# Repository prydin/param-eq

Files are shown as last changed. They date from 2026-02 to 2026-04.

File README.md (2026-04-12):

# Parametric EQ to DSP Playground

This project started as a focused experiment: build a practical, hardware-controlled parametric equalizer.
Along the way it grew into something broader: a general-purpose DSP platform for real-time audio processing,
instrumentation, and UI experiments.

What began as "just three EQ bands" now includes filter control, combined response visualization,
VU metering, spectrum visualization, and a register-based control/data protocol between two MCUs.

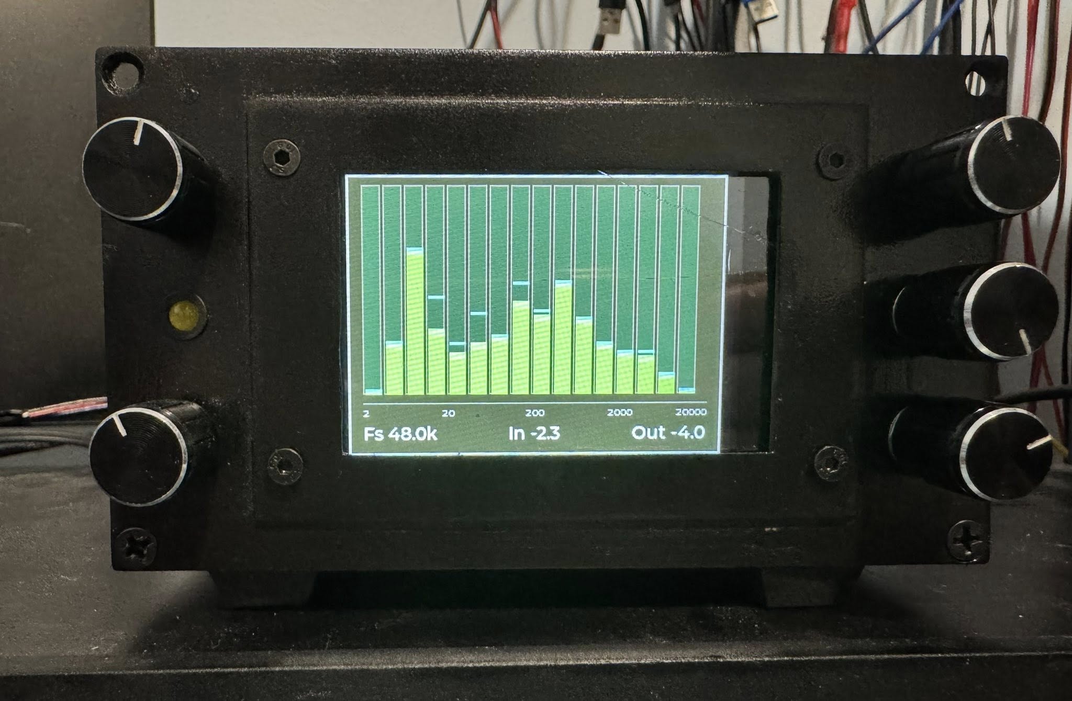
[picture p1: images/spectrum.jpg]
Spectrum

Filter design
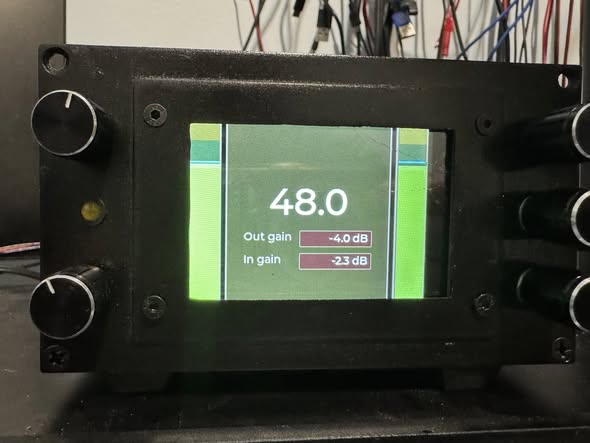
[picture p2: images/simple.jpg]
Simple UI

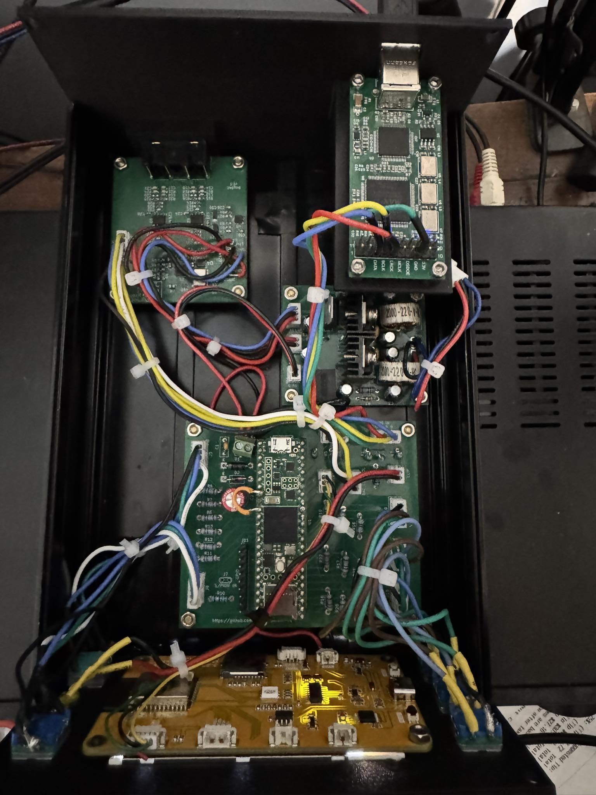
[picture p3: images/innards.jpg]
Interior


## Project Story

The original goal was simple:

1. Build a hands-on parametric EQ with physical controls.
2. Show the selected filter behavior and resulting response in real time.
3. Keep the software and hardware open enough to keep evolving.

That third point changed everything. Once the DSP core and UI link were stable, it became obvious that
the architecture could do far more than EQ alone. The codebase now behaves more like a modular DSP
workbench than a single-purpose effect.

## Architecture

The system uses two processors, each doing the job it is best at.

### Teensy 4.1: Audio DSP Engine

- Handles real-time signal processing.
- Computes filter behavior and response data.
- Publishes metering and spectrum data.
- Maintains the parameter/register state that the UI consumes.

Why Teensy 4.1:

- Cortex-M7 performance is excellent for this class of project.
- Floating-point math is fast enough to keep filter code readable and robust.
- Great ecosystem for embedded audio prototyping.

### ESP32 CYD: UI Processor

The UI runs on a CYD (Cheap Yellow Display), which is an ESP32-based board with an integrated TFT.

- Renders LVGL-based UI modes.
- Reads user input from rotary encoders/buttons.
- Displays EQ response, VU, and spectrum information.
- Exchanges register updates with the Teensy via I2C.

### Interconnect: Register-Based I2C Protocol

Communication between DSP and UI uses compact register messages over I2C.

- Control parameters and mode changes flow from UI-side interactions.
- DSP publishes status, levels, and spectrum bins back to UI.
- Commit-style register updates keep state transitions predictable.

## UI Modes

The UI currently provides three main modes, each optimized for a different use case.

### 1) Detailed EQ Mode

Purpose: precise tuning and analysis.

- Displays selected filter response and optional combined response.
- Shows active filter type and selected filter band.
- Shows numeric parameter values including frequency, gain, Q, sample rate, and level settings.
- Intended for surgical parameter work.

### 2) Simple Meter Mode

Purpose: quick operating view.

- Large, easy-to-read core values.
- Stereo VU metering with ballistic behavior and peak hold.
- Designed for "use while listening" rather than deep editing.

### 3) Spectrum Analyzer Mode

Purpose: visualize real-time spectral behavior.

- Real-time spectrum bars with smoothing and peak hold.
- Log-style frequency scale and supplemental operating info.
- Useful for spotting trends, resonances, and level distribution.

### Filter Parameter Popup Overlay

When operating in Simple or Spectrum mode, parameter changes can trigger a framed popup showing key
filter settings (band, type, frequency, gain, and Q). The popup auto-hides after inactivity, and can
be gated by user-input state so remote/background updates do not constantly interrupt the view.

## Current Scope

- Multi-band parametric EQ control.
- Low shelf, high shelf, and peak filter workflows.
- Dual-MCU DSP/UI split with robust register transport.
- Multiple operator-focused UI modes.
- Real-time VU and spectrum visualization.

## Where It Is Heading

Long term, the plan is to fold this work into a DAC/DSP/preamplifier build.
This repository is the proving ground for that hardware/software stack.

## Acknowledgements

Big thanks to the diyAudio.com community.

Many design choices, implementation refinements, and troubleshooting ideas were inspired by the
knowledge shared by diyAudio members. The project benefited directly from their practical guidance,
experience, and generosity in public discussion threads.

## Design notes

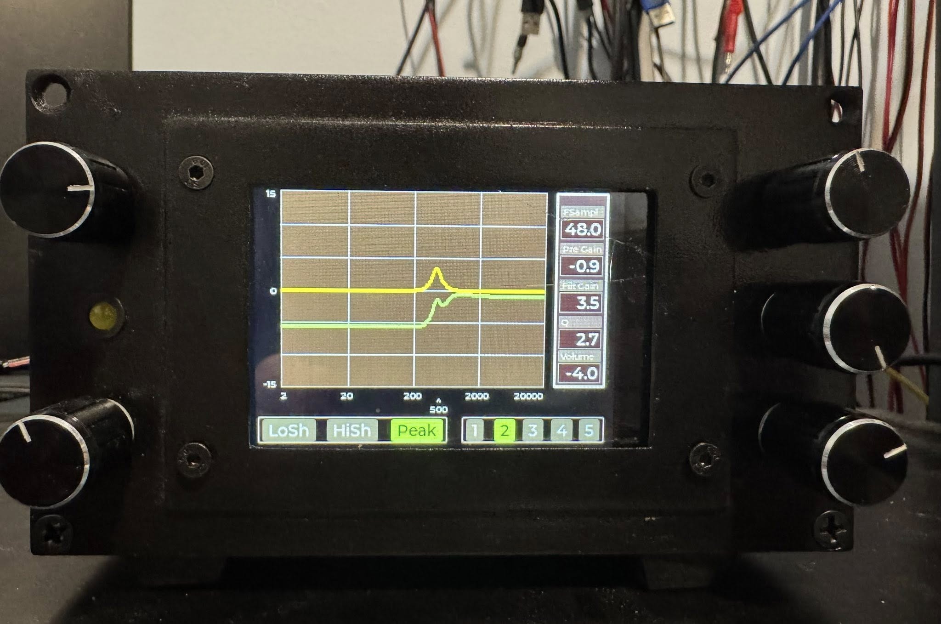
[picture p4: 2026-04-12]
images/eq.jpg

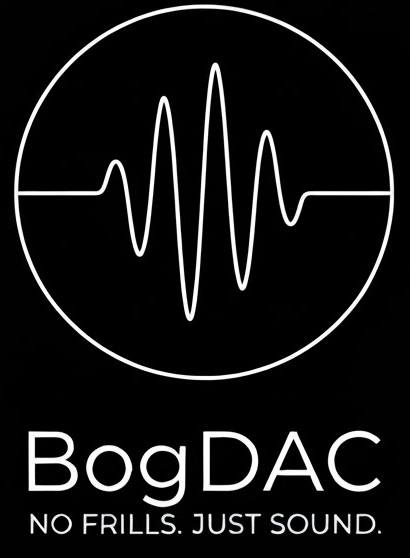
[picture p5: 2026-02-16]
kicad/dac/bogdac.jpg

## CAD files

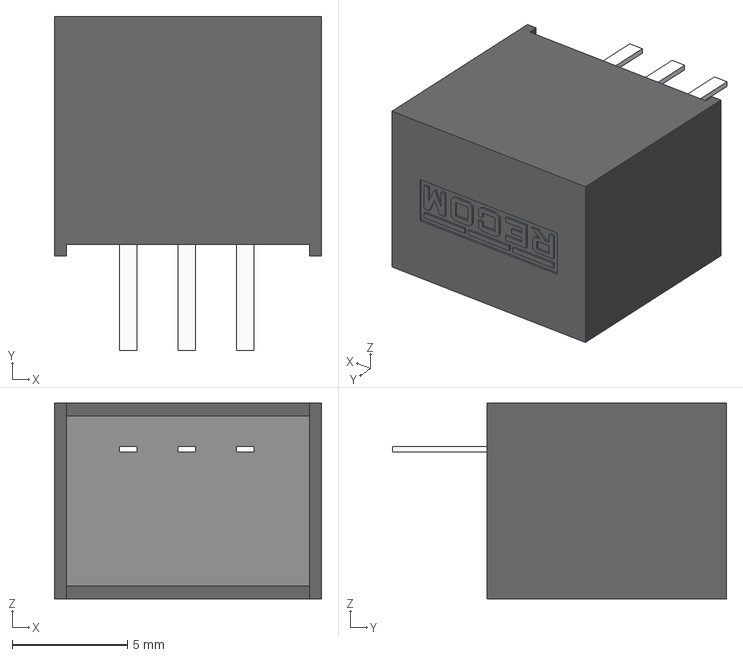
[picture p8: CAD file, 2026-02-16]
kicad/regulator/footprints/R-78E5.0-1.0.step
11.6 x 14.5 x 8.50 mm

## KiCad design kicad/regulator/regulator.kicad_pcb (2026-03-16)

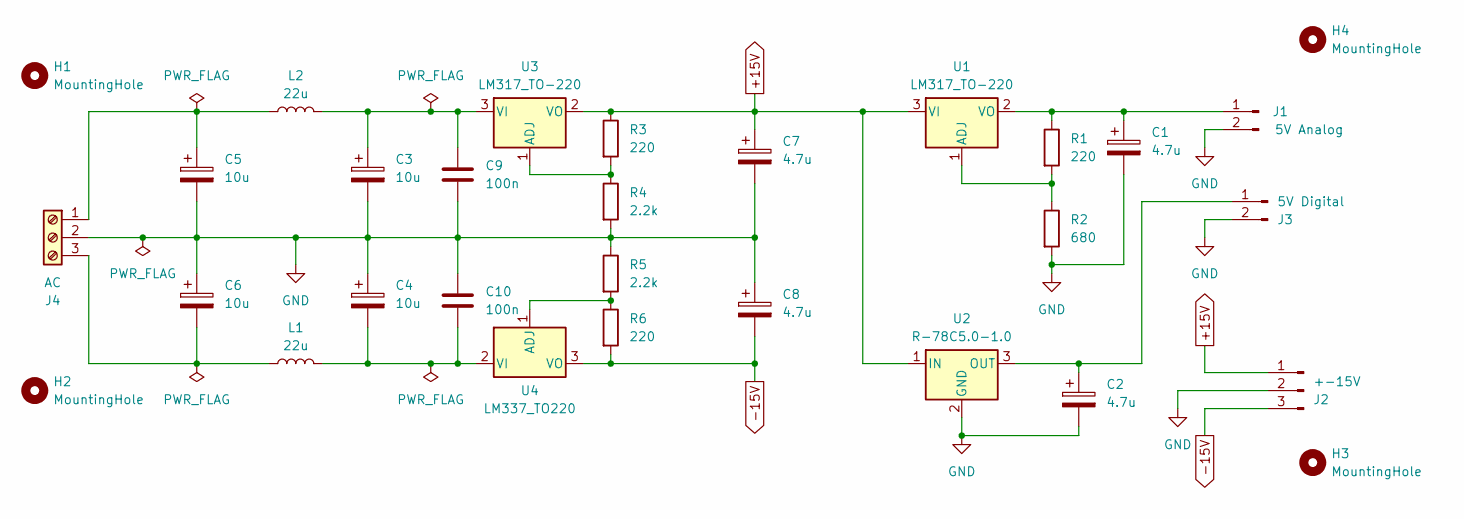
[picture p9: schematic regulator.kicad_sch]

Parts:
C1, C2, C7, C8: 4.7u; CP_Radial_D4.0mm_P1.50mm
C3, C4, C5, C6: 10u; CP_Radial_D4.0mm_P1.50mm
C9, C10: 100n; C_Disc_D3.8mm_W2.6mm_P2.50mm
H1, H2, H3, H4: MountingHole; MountingHole_3.2mm_M3
J1: 5V Analog; JST_PH_B2B-PH-K_1x02_P2.00mm_Vertical
J2: +-15V; JST_PH_B3B-PH-K_1x03_P2.00mm_Vertical
J3: 5V Digital; JST_PH_B2B-PH-K_1x02_P2.00mm_Vertical
J4: AC; TerminalBlock_Phoenix_MPT-0,5-3-2.54_1x03_P2.54mm_Horizontal
L1, L2: 22u; L_Toroid_Vertical_L17.8mm_W8.1mm_P7.62mm_Bourns_5700
R1, R3, R6: 220; R_Axial_DIN0204_L3.6mm_D1.6mm_P7.62mm_Horizontal
R2: 680; R_Axial_DIN0204_L3.6mm_D1.6mm_P7.62mm_Horizontal
R4, R5: 2.2k; R_Axial_DIN0204_L3.6mm_D1.6mm_P7.62mm_Horizontal
U1, U3: LM317_TO-220; TO-220-3_Vertical
U2: R-78C5.0-1.0; Converter_DCDC_RECOM_R-78E-0.5_THT
U4: LM337_TO220; TO-220-3_Vertical

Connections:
+15V: C7.1, J2.1, R3.1, U1.3 (VI), U2.1 (IN), U3.2 (VO)
-15V: C8.2, J2.3, R6.2, U4.3 (VO)
GND: C1.2, C2.2, C3.2, C4.1, C5.2, C6.1, C7.2, C8.1, C9.2, C10.1, J1.2, J2.2, J3.2, J4.2, R2.2, R4.2, R5.1, U2.2 (GND)
unnamed: C1.1, J1.1, R1.1, U1.2 (VO)
unnamed: C2.1, J3.1, U2.3 (OUT)
unnamed: C5.1, J4.1, L2.1
unnamed: C6.2, J4.3, L1.1
unnamed: R1.2, R2.1, U1.1 (ADJ)
unnamed: R3.2, R4.1, U3.1 (ADJ)
unnamed: C3.1, C9.1, L2.2, U3.3 (VI)
unnamed: R5.2, R6.1, U4.1 (ADJ)
unnamed: C4.2, C10.2, L1.2, U4.2 (VI)

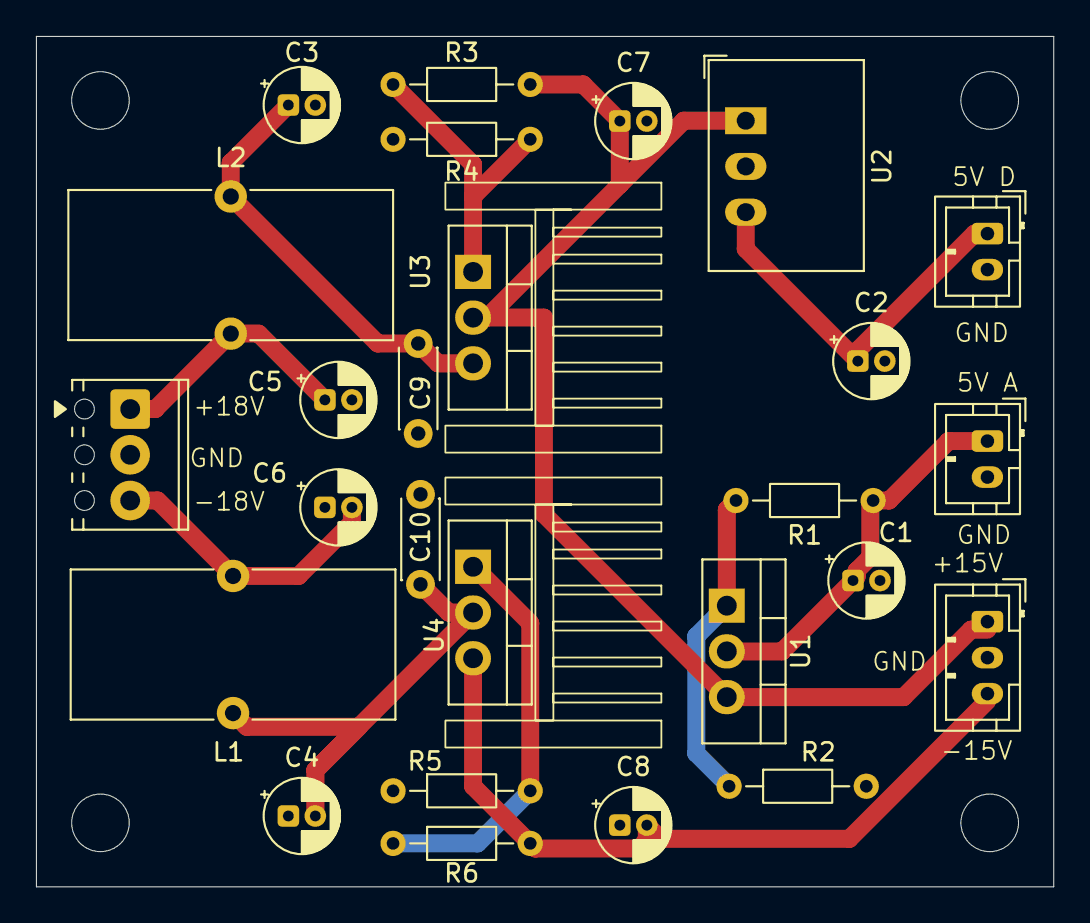
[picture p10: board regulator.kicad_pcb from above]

Board: 2 copper layers, 56.5 x 47.2 mm, 30 parts (0 on the bottom side), 12 nets.

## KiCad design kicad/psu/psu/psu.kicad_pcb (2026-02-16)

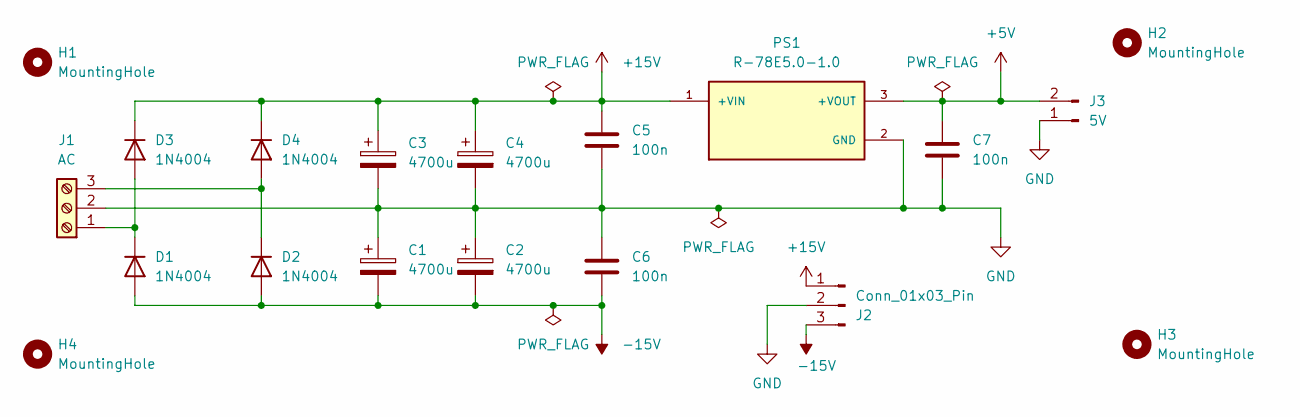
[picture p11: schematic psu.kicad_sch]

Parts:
C1, C2, C3, C4: 4700u; CP_Radial_D16.0mm_P7.50mm
C5, C6, C7: 100n; C_Disc_D5.0mm_W2.5mm_P5.00mm
D1, D2, D3, D4: 1N4004; D_DO-41_SOD81_P10.16mm_Horizontal
H1, H2, H3, H4: MountingHole; MountingHole_3.2mm_M3
J1: AC; TerminalBlock_Phoenix_MPT-0,5-3-2.54_1x03_P2.54mm_Horizontal
J2: Conn_01x03_Pin; JST_PH_B3B-PH-K_1x03_P2.00mm_Vertical
J3: 5V; JST_PH_B2B-PH-K_1x02_P2.00mm_Vertical
PS1: R-78E5.0-1.0; CONV_R-78E5.0-1.0; PARTREV 6

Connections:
+5V: C7.1, J3.2, PS1.3 (+VOUT)
+15V: C3.1, C4.1, C5.1, D3.1 (K), D4.1 (K), J2.1, PS1.1 (+VIN)
-15V: C1.2, C2.2, C6.2, D1.2 (A), D2.2 (A), J2.3
GND: C1.1, C2.1, C3.2, C4.2, C5.2, C6.1, C7.2, J1.2, J2.2, J3.1, PS1.2 (GND)
unnamed: D1.1 (K), D3.2 (A), J1.1
unnamed: D2.1 (K), D4.2 (A), J1.3

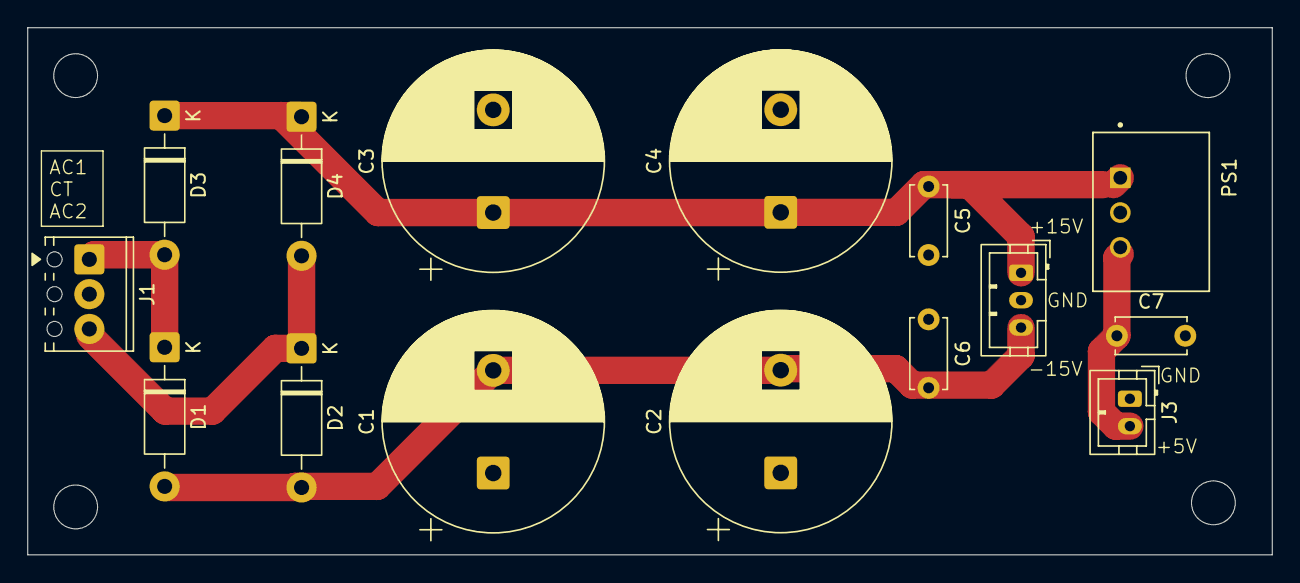
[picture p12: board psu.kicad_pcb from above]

Board: 2 copper layers, 90.9 x 38.5 mm, 19 parts (0 on the bottom side), 6 nets.

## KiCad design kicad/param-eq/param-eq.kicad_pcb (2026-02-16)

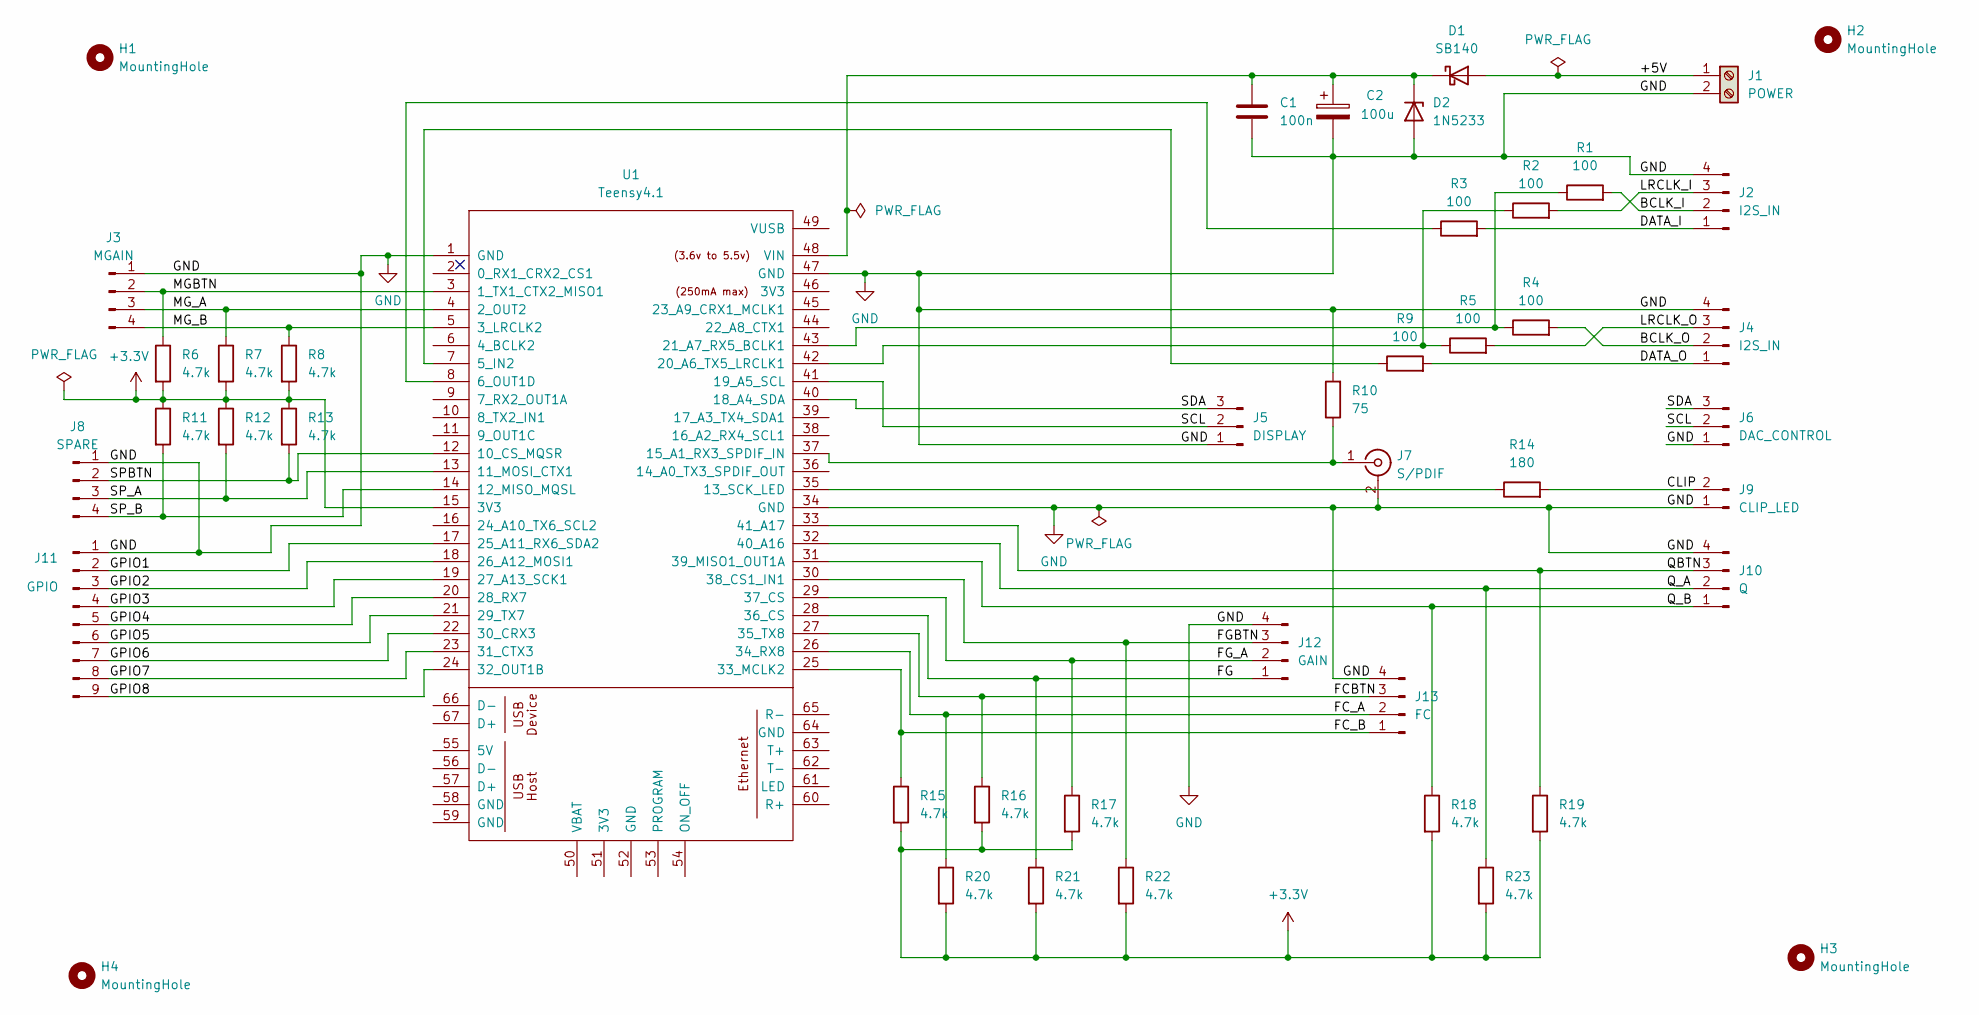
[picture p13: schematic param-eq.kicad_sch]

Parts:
C1: 100n; C_Rect_L7.2mm_W3.0mm_P5.00mm_FKS2_FKP2_MKS2_MKP2_HandSolder
C2: 100u; CP_Radial_D8.0mm_P5.00mm
D1: SB140; D_DO-41_SOD81_P10.16mm_Horizontal
D2: 1N5233; D_DO-41_SOD81_P10.16mm_Horizontal
H1, H2, H3, H4: MountingHole; MountingHole_3.2mm_M3
J1: POWER; TerminalBlock_4Ucon_1x02_P3.50mm_Horizontal
J2, J4: I2S_IN; JST_PH_B4B-PH-K_1x04_P2.00mm_Vertical
J3: MGAIN; JST_PH_B4B-PH-K_1x04_P2.00mm_Vertical
J5: DISPLAY; JST_PH_B3B-PH-K_1x03_P2.00mm_Vertical
J6: DAC_CONTROL; JST_PH_B3B-PH-K_1x03_P2.00mm_Vertical
J7: S/PDIF; TestPoint_2Pads_Pitch2.54mm_Drill0.8mm
J8: SPARE; JST_PH_B4B-PH-K_1x04_P2.00mm_Vertical
J9: CLIP_LED; JST_PH_B2B-PH-K_1x02_P2.00mm_Vertical
J10: Q; JST_PH_B4B-PH-K_1x04_P2.00mm_Vertical
J11: GPIO; PinHeader_1x09_P2.54mm_Vertical
J12: GAIN; JST_PH_B4B-PH-K_1x04_P2.00mm_Vertical
J13: FC; JST_PH_B4B-PH-K_1x04_P2.00mm_Vertical
R1, R2, R3, R4, R5, R9: 100; R_Axial_DIN0204_L3.6mm_D1.6mm_P2.54mm_Vertical
R6, R7, R8, R11, R12, R13, R15, R16, R17, R18, R19, R20, R21, R22, R23: 4.7k; R_Axial_DIN0204_L3.6mm_D1.6mm_P7.62mm_Horizontal_HandSolder
R10: 75; R_Axial_DIN0204_L3.6mm_D1.6mm_P7.62mm_Horizontal_HandSolder
R14: 180; R_Axial_DIN0204_L3.6mm_D1.6mm_P7.62mm_Horizontal_HandSolder
U1: Teensy4.1; Teensy41

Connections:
+3.3V: R6.2, R7.2, R8.2, R11.1, R12.1, R13.1, R15.2, R16.2, R17.2, R18.2, R19.2, R20.2, R21.2, R22.2, R23.2, U1.15 (3V3)
/+5V: D1.2 (A), J1.1
/BCLK_I: J2.2, R1.2
/BCLK_O: J4.2, R4.2
/CLIP: J9.2, R14.2
/DATA_I: J2.1, R3.2
/DATA_O: J4.1, R9.2
/FCBTN: J13.3, R16.1, U1.27 (35_TX8)
/FC_A: J13.2, R20.1, U1.26 (34_RX8)
/FC_B: J13.1, R15.1, U1.25 (33_MCLK2)
/FG: J12.1, R21.1, U1.28 (36_CS)
/FGBTN: J12.3, R22.1, U1.30 (38_CS1_IN1)
/FG_A: J12.2, R17.1, U1.29 (37_CS)
/GPIO1: J11.2, U1.17 (25_A11_RX6_SDA2)
/GPIO2: J11.3, U1.18 (26_A12_MOSI1)
/GPIO3: J11.4, U1.19 (27_A13_SCK1)
/GPIO4: J11.5, U1.20 (28_RX7)
/GPIO5: J11.6, U1.21 (29_TX7)
/GPIO6: J11.7, U1.22 (30_CRX3)
/GPIO7: J11.8, U1.23 (31_CTX3)
/GPIO8: J11.9, U1.24 (32_OUT1B)
/LRCLK_I: J2.3, R2.2
/LRCLK_O: J4.3, R5.2
/MGBTN: J3.2, R6.1, U1.3 (1_TX1_CTX2_MISO1)
/MG_A: J3.3, R7.1, U1.4 (2_OUT2)
/MG_B: J3.4, R8.1, U1.5 (3_LRCLK2)
/QBTN: J10.3, R19.1, U1.33 (41_A17)
/Q_A: J10.2, R23.1, U1.32 (40_A16)
/Q_B: J10.1, R18.1, U1.31 (39_MISO1_OUT1A)
/SCL: J5.2, J6.2, U1.41 (19_A5_SCL)
/SDA: J5.3, J6.3, U1.40 (18_A4_SDA)
/SPBTN: J8.2, R13.2, U1.12 (10_CS_MQSR)
/SP_A: J8.3, R12.2, U1.13 (11_MOSI_CTX1)
/SP_B: J8.4, R11.2, U1.14 (12_MISO_MQSL)
GND: C1.2, C2.2, D2.2 (A), J1.2, J2.4, J3.1, J4.4, J5.1, J6.1, J7.2 (Ext), J8.1, J9.1, J10.4, J11.1, J12.4, J13.4, R10.2, U1.1 (GND), U1.34 (GND), U1.47 (GND)
unnamed: C1.1, C2.1, D1.1 (K), D2.1 (K), U1.48 (VIN)
unnamed: J7.1 (In), R10.1, U1.37 (15_A1_RX3_SPDIF_IN)
unnamed: R9.1, U1.7 (5_IN2)
unnamed: R3.1, U1.8 (6_OUT1D)
unnamed: R14.1, U1.35 (13_SCK_LED)
unnamed: R2.1, R5.1, U1.42 (20_A6_TX5_LRCLK1)
unnamed: R1.1, R4.1, U1.43 (21_A7_RX5_BCLK1)

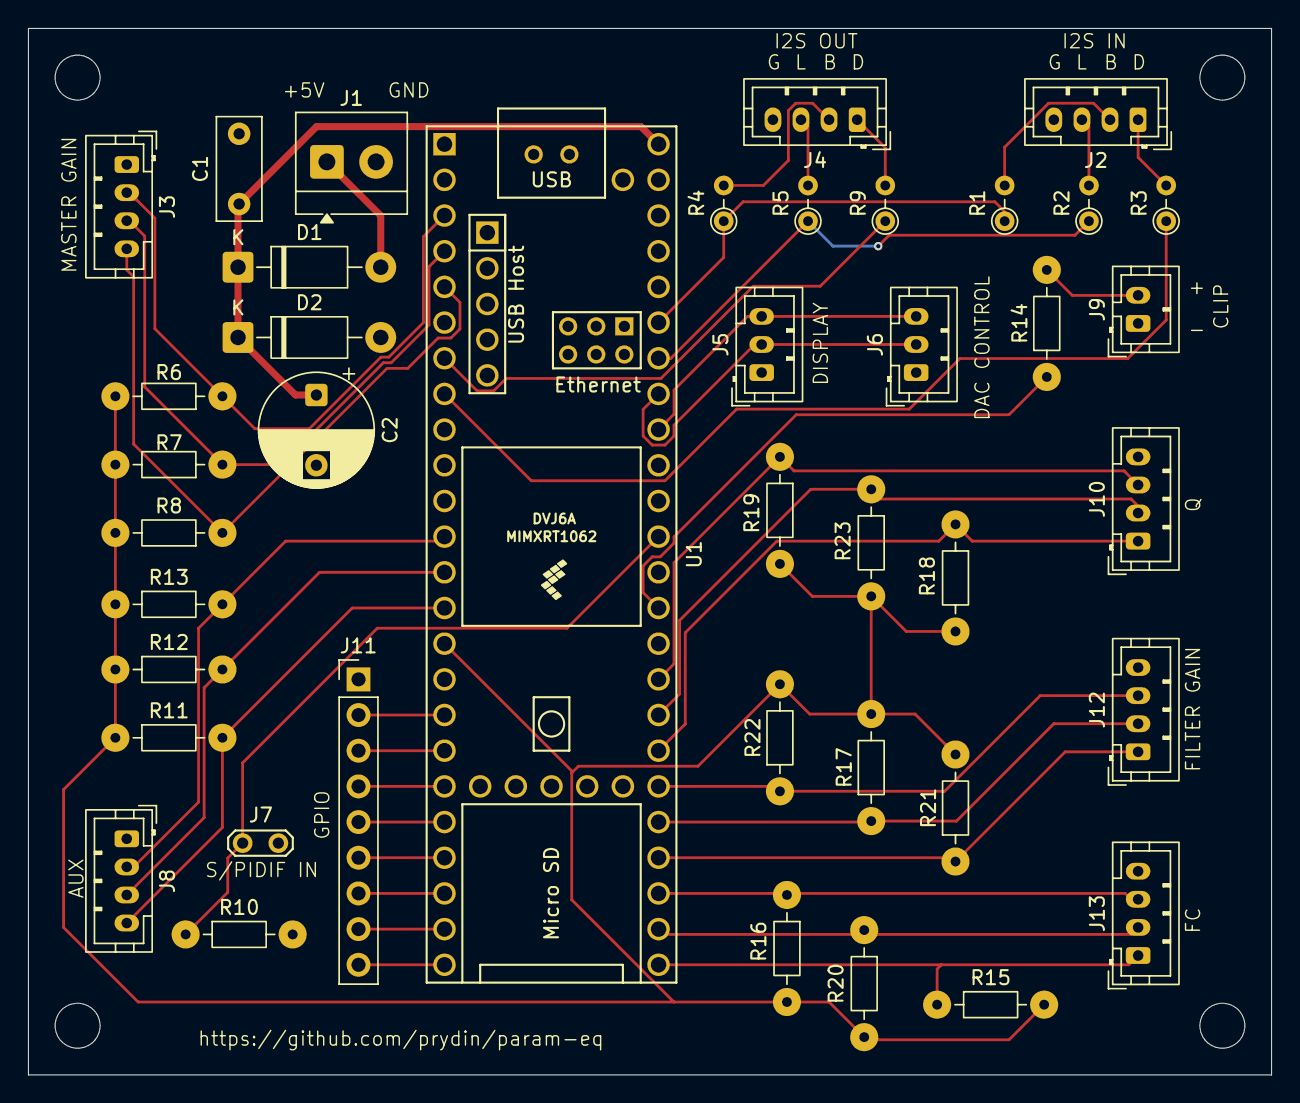
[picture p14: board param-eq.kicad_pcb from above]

Board: 2 copper layers, 88.5 x 74.5 mm, 45 parts (0 on the bottom side), 42 nets.

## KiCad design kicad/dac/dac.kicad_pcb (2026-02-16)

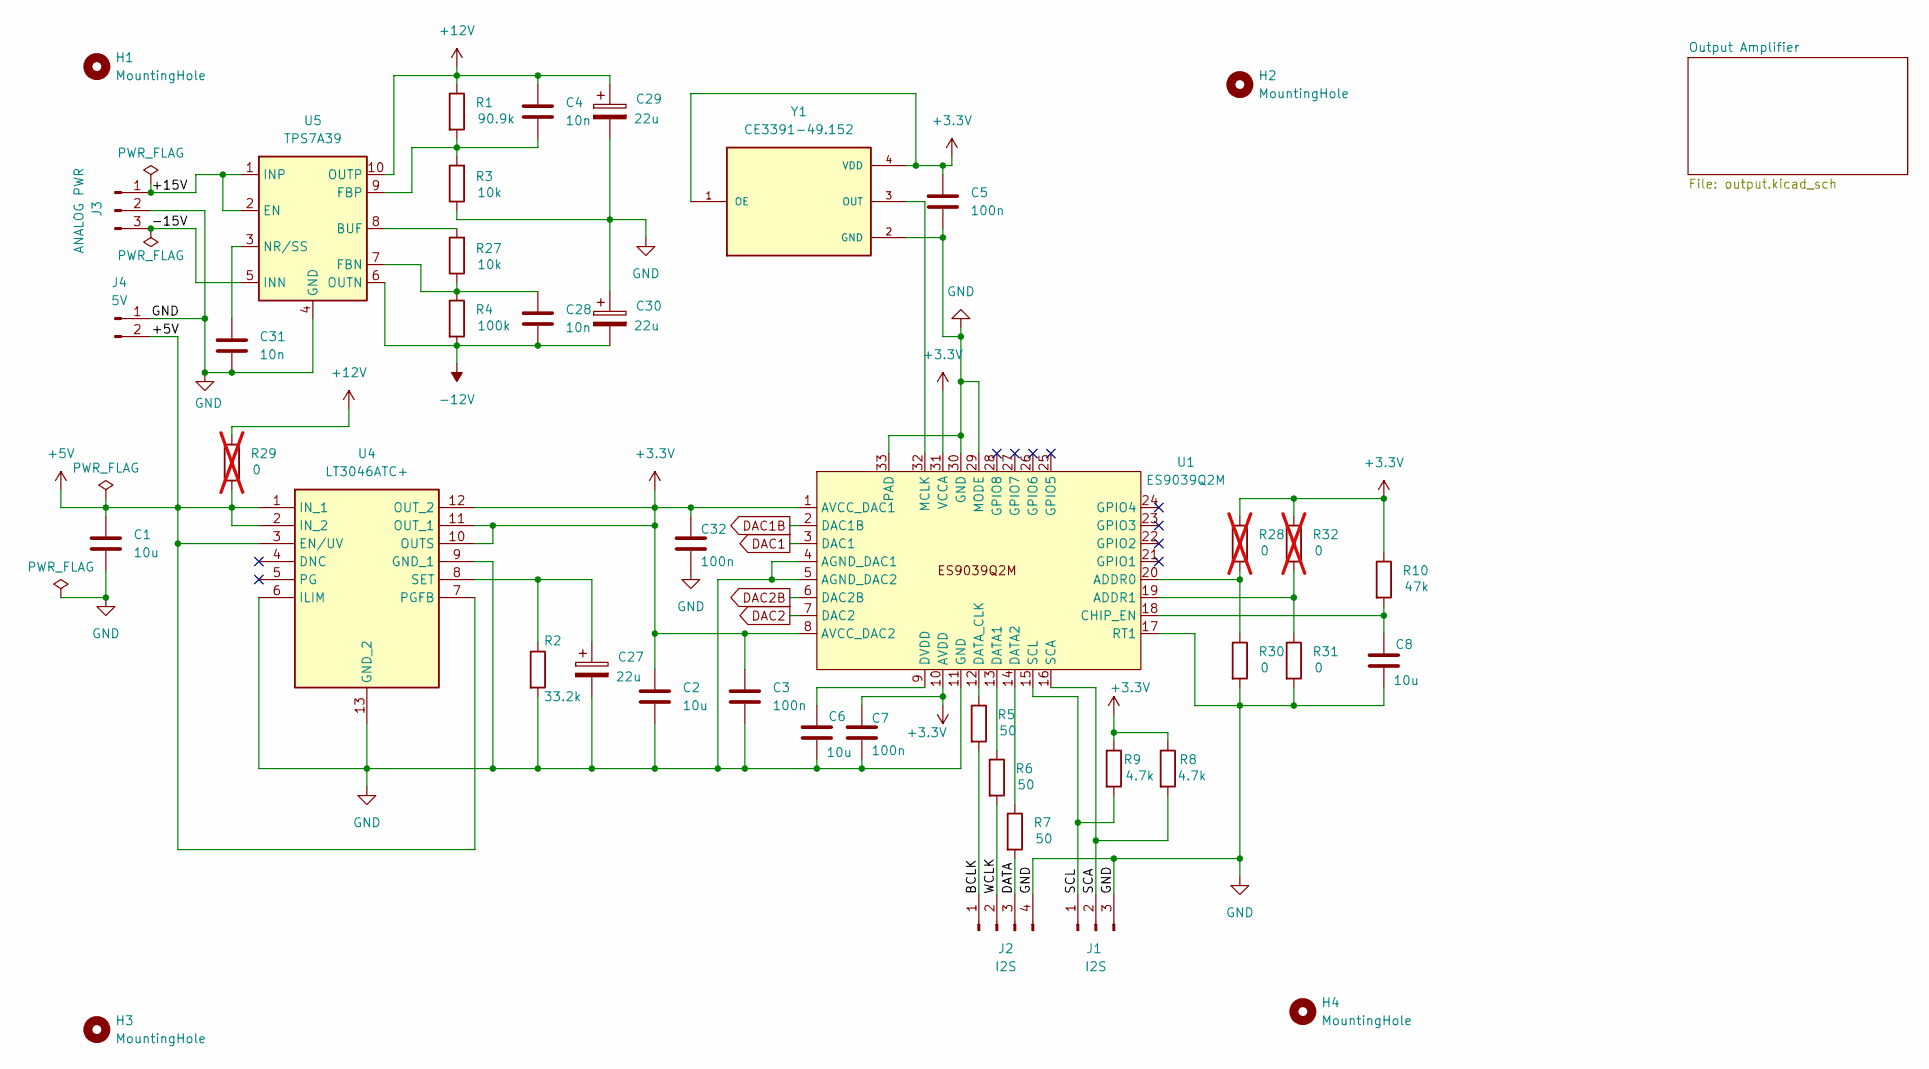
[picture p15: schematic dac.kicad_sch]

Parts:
C1, C2, C6, C8: 10u; C_0805_2012Metric
C3, C7, C32: 100n; C_0402_1005Metric
C4, C28, C31: 10n; C_0603_1608Metric
C5: 100n; C_0603_1608Metric
C27, C29, C30: 22u; CP_EIA-3216-10_Kemet-I_HandSolder
H1: MountingHole; MountingHole_3.2mm_M3
H2, H3, H4: MountingHole
J1: I2S; JST_PH_B3B-PH-K_1x03_P2.00mm_Vertical
J2: I2S; JST_PH_B4B-PH-K_1x04_P2.00mm_Vertical
J3: ANALOG PWR; JST_PH_B3B-PH-K_1x03_P2.00mm_Vertical
J4: 5V; JST_PH_B2B-PH-K_1x02_P2.00mm_Vertical
R1: 90.9k; R_0603_1608Metric_Pad0.98x0.95mm_HandSolder
R2: 33.2k; R_0603_1608Metric_Pad0.98x0.95mm_HandSolder
R3, R27: 10k; R_0603_1608Metric_Pad0.98x0.95mm_HandSolder
R4: 100k; R_0603_1608Metric_Pad0.98x0.95mm_HandSolder
R5, R6, R7: 50; R_0603_1608Metric_Pad0.98x0.95mm_HandSolder
R8, R9: 4.7k; R_0603_1608Metric_Pad0.98x0.95mm_HandSolder
R10: 47k; R_0603_1608Metric_Pad0.98x0.95mm_HandSolder
R28, R29, R32: 0; R_0603_1608Metric_Pad0.98x0.95mm_HandSolder; not fitted
R30, R31: 0; R_0603_1608Metric_Pad0.98x0.95mm_HandSolder
U1: ES9039Q2M; UFQFPN-32-1EP_5x5mm_P0.5mm_EP3.5x3.5mm
U4: LT3046ATC+; SON45P300X300X80-13N-D; Mouser Part Number 700-LT3046ATC+
U5: TPS7A39; Texas_S-PVSON-N10_ThermalVias
Y1: CE3391-49.152; Oscillator_SMD_Diodes_FN-4Pin_7.0x5.0mm; PARTREV NA

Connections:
+3.3V: C2.1, C3.1, C5.1, C7.1, C32.1, R8.1, R9.1, R10.1, R28.1, R32.1, U1.1 (AVCC_DAC1), U1.8 (AVCC_DAC2), U1.10 (AVDD), U1.31 (VCCA), U4.10 (OUTS), U4.11 (OUT_1), U4.12 (OUT_2), Y1.1 (OE), Y1.4 (VDD)
+5V: C1.1, J4.2, R29.2, U4.1 (IN_1), U4.2 (IN_2), U4.3 (EN/UV), U4.7 (PGFB)
+12V: C4.1, C29.1, R1.1, R29.1, U5.10 (OUTP); also elsewhere on the board
-12V: C28.2, C30.2, R4.2, U5.6 (OUTN); also elsewhere on the board
/+15V: J3.1, U5.1 (INP), U5.2 (EN)
/-15V: J3.3, U5.5 (INN)
/BCLK: J2.1, R5.2
/DATA: J2.3, R7.2
/SCA: J1.2, R8.2, U1.16 (SCA)
/SCL: J1.1, R9.2, U1.15 (SCL)
/WCLK: J2.2, R6.2
DAC1: U1.3 (DAC1); also elsewhere on the board
DAC1B: U1.2 (DAC1B); also elsewhere on the board
DAC2: U1.7 (DAC2); also elsewhere on the board
DAC2B: U1.6 (DAC2B); also elsewhere on the board
GND: C1.2, C2.2, C3.2, C5.2, C6.2, C7.2, C8.2, C27.2, C29.2, C30.1, C31.2, C32.2, J1.3, J2.4, J3.2, J4.1, R2.2, R3.1, R30.2, R31.2, U1.4 (AGND_DAC1), U1.5 (AGND_DAC2), U1.11 (GND), U1.17 (RT1), U1.29 (MODE), U1.30 (GND), U1.33 (PAD), U4.6 (ILIM), U4.9 (GND_1), U4.13 (GND_2), U5.4 (GND), U5.11 (GND), Y1.2 (GND); also elsewhere on the board
unnamed: R28.2, R30.1, U1.20 (ADDR0)
unnamed: R31.1, R32.2, U1.19 (ADDR1)
unnamed: C8.1, R10.2, U1.18 (CHIP_EN)
unnamed: R6.1, U1.13 (DATA1)
unnamed: R7.1, U1.14 (DATA2)
unnamed: R5.1, U1.12 (DATA_CLK)
unnamed: C6.1, U1.9 (DVDD)
unnamed: U1.32 (MCLK), Y1.3 (OUT)
unnamed: C27.1, R2.1, U4.8 (SET)
unnamed: R27.2, U5.8 (BUF)
unnamed: C28.1, R4.1, R27.1, U5.7 (FBN)
unnamed: C4.2, R1.2, R3.2, U5.9 (FBP)
unnamed: C31.1, U5.3 (NR/SS)

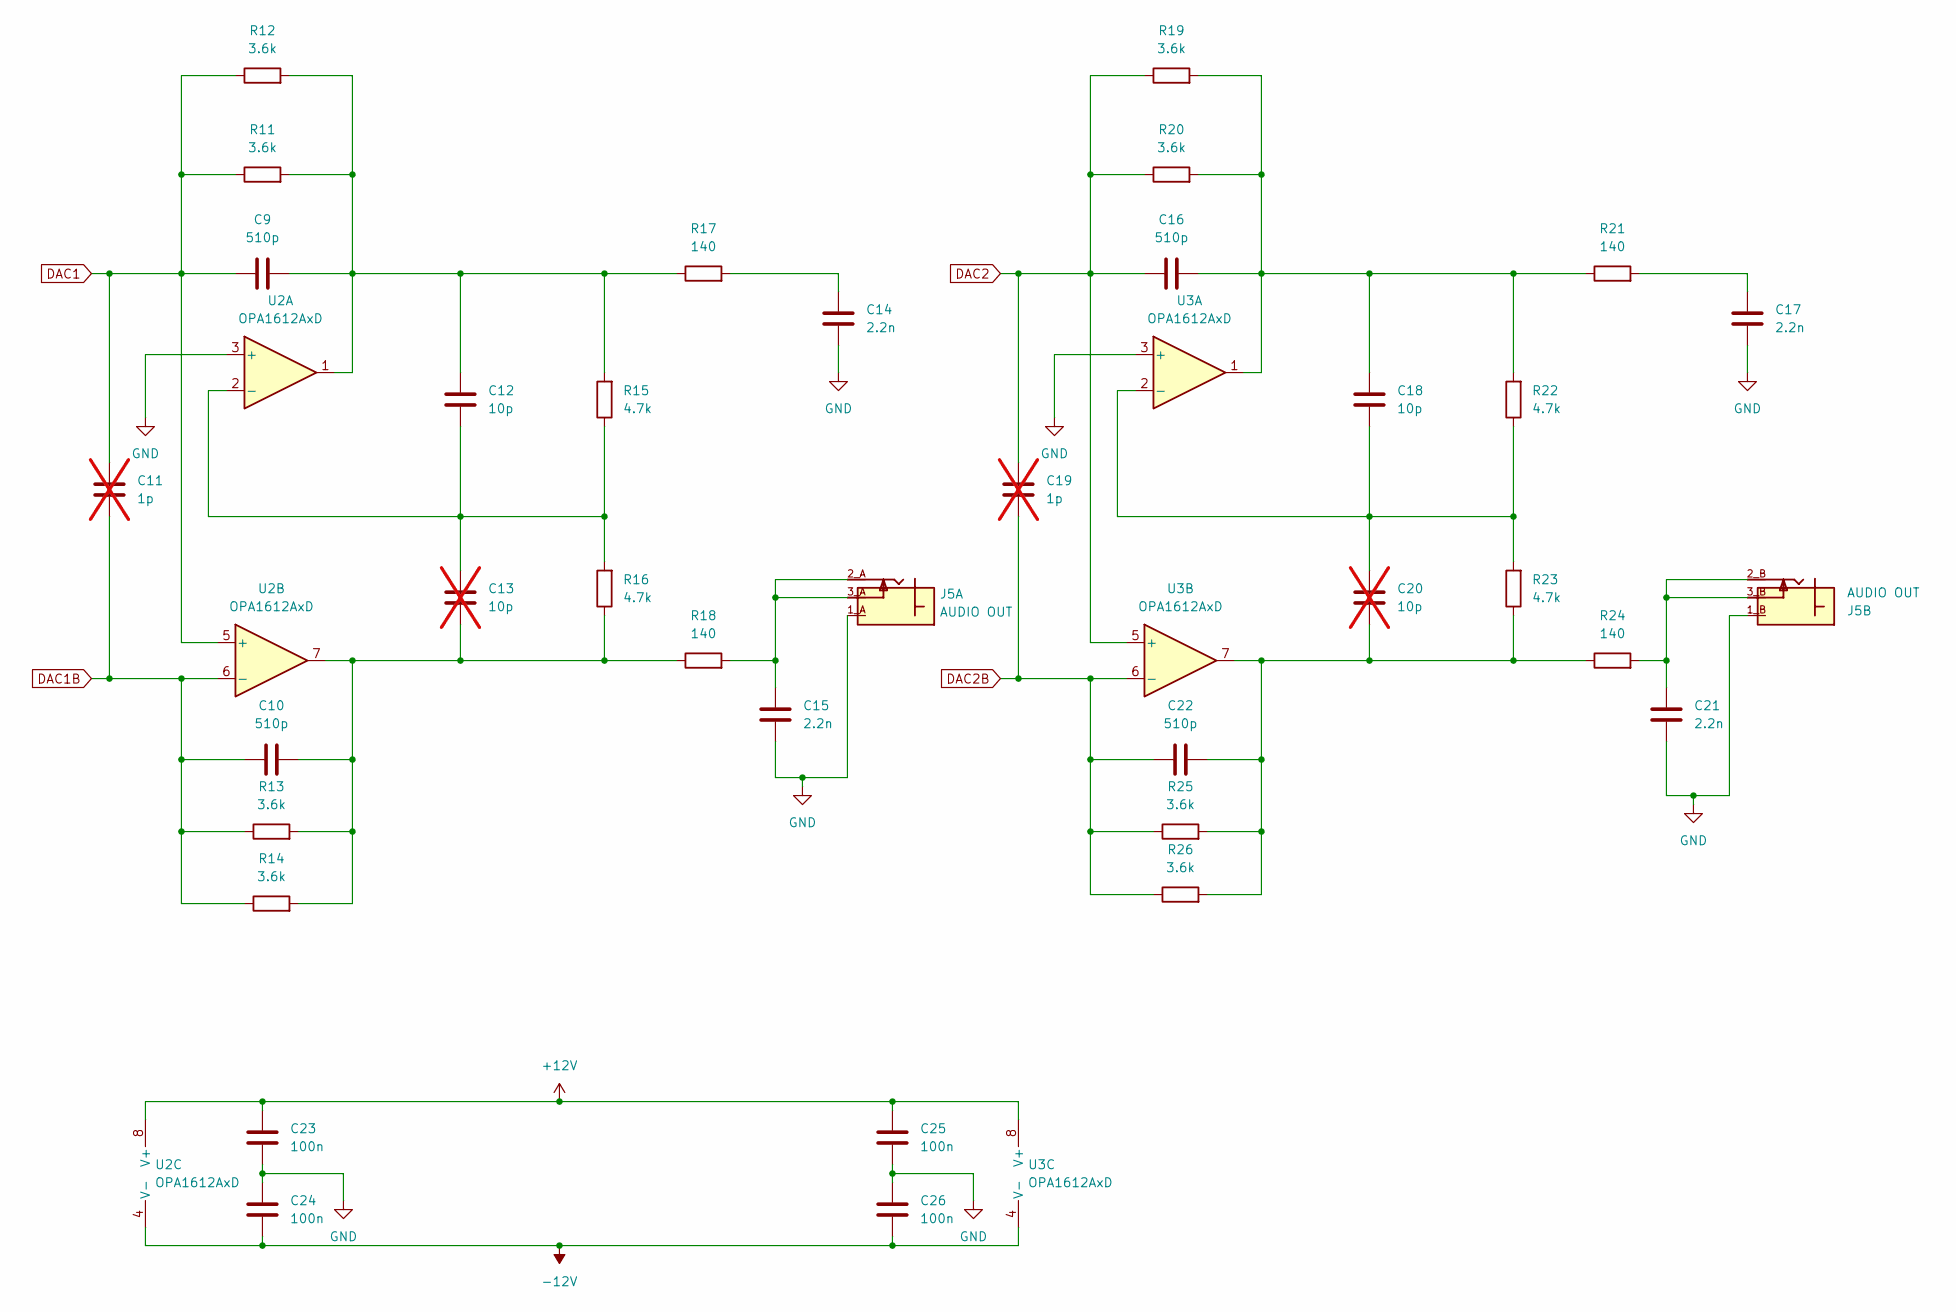
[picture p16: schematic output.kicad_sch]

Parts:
C9, C10, C16, C22: 510p; C_0603_1608Metric
C11, C19: 1p; C_0603_1608Metric; not fitted
C12, C18: 10p; C_0603_1608Metric
C13, C20: 10p; C_0603_1608Metric; not fitted
C14, C15, C17, C21: 2.2n; C_0603_1608Metric
C23, C24, C25, C26: 100n; C_0603_1608Metric
J5: AUDIO OUT; SWITCHCRAFT_PJRAN2X1U01AUX
R11, R12, R13, R14, R19, R20, R25, R26: 3.6k; R_0603_1608Metric_Pad0.98x0.95mm_HandSolder
R15, R16, R22, R23: 4.7k; R_0603_1608Metric_Pad0.98x0.95mm_HandSolder
R17, R18, R21, R24: 140; R_0603_1608Metric_Pad0.98x0.95mm_HandSolder
U2, U3: OPA1612AxD; SOIC-8_3.9x4.9mm_P1.27mm

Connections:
+12V: C23.2, C25.2, U2.8 (V+), U3.8 (V+); also elsewhere on the board
-12V: C24.1, C26.1, U2.4 (V-), U3.4 (V-); also elsewhere on the board
DAC1: C9.1, C11.2, R11.1, R12.1, U2.5 (+); also elsewhere on the board
DAC1B: C10.1, C11.1, R13.1, R14.1, U2.6 (-); also elsewhere on the board
DAC2: C16.1, C19.2, R19.1, R20.1, U3.5 (+); also elsewhere on the board
DAC2B: C19.1, C22.1, R25.1, R26.1, U3.6 (-); also elsewhere on the board
GND: C14.1, C15.1, C17.1, C21.1, C23.1, C24.2, C25.1, C26.2, J5.1_A, J5.1_B, U2.3 (+), U3.3 (+); also elsewhere on the board
unnamed: C10.2, C13.1, R13.2, R14.2, R16.1, R18.1, U2.7
unnamed: C9.2, C12.2, R11.2, R12.2, R15.2, R17.1, U2.1
unnamed: C14.2, R17.2
unnamed: C15.2, J5.2_A, J5.3_A, R18.2
unnamed: C16.2, C18.2, R19.2, R20.2, R21.1, R22.2, U3.1
unnamed: C17.2, R21.2
unnamed: C20.1, C22.2, R23.1, R24.1, R25.2, R26.2, U3.7
unnamed: C21.2, J5.2_B, J5.3_B, R24.2
unnamed: C12.1, C13.2, R15.1, R16.2, U2.2 (-)
unnamed: C18.1, C20.2, R22.1, R23.2, U3.2 (-)

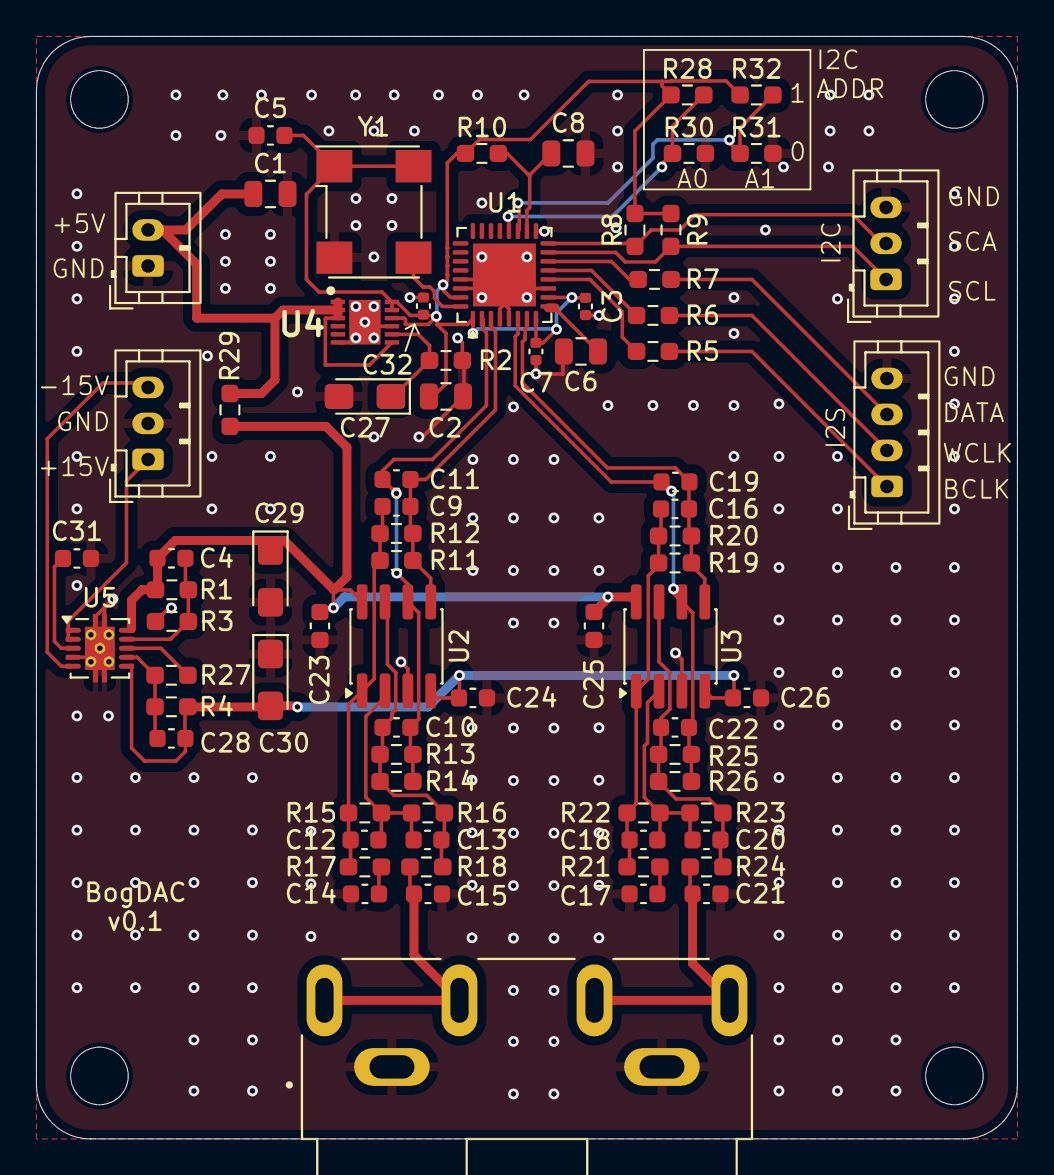
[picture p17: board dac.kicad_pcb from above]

Board: 4 copper layers, 54.5 x 61.2 mm, 79 parts (0 on the bottom side), 39 nets.

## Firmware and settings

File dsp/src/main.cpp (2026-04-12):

// Copyright (c) 2026 Pontus Rydin
// SPDX-License-Identifier: MIT
//
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
 * This file implements a real-time audio parametric equalizer system using the
 * Teensy Audio Library.
 * It provides three-band equalization (low, mid, high) with selectable filter types (low shelf,
 * high shelf, peaking EQ). User controls include rotary encoders for frequency, gain, and Q
 * adjustment, along with pushbuttons for filter band and type selection.
 *
 * The system generates a test waveform, processes it through stereo biquad filters, and outputs
 * the result via I2S. Filter coefficients and parameters are transmitted to an external display
 * via I2C communication.
 *
 * @note Requires Teensy Audio Library, OneButton, ErriezCRC32, and AcceleratedEncoder libraries.
 * @note I2C display address is hardcoded to 0xb1ce.
 * @note Audio processing uses floating-point biquad filters for precise frequency response control.
 */
#include <Teensy4i2s.h>
#include <Wire.h>
#include <SD.h>
#include <SerialFlash.h>
#include <OneButton.h>
#include <ErriezCRC32.h>
#include <stdlib.h>
#include "../../common/filter.h"
#include "../../common/constants.h"
#include "audio_pipeline/filter_biquad_f.h"
#include "audio_pipeline/audio_square_wave.h"
#include "audio_pipeline/audio_gain.h"
#include "audio_pipeline/audio_rms.h"
#include "audio_pipeline/audio_peak.h"
#include "audio_pipeline/audio_controller.h"
#include "audio_pipeline/audio_spectrum_td.h"
#include "AcceleratedEncoder.h"
#include "netconv.h"
#include "persistence.h"
#include "display.h"

// #define TESTMODE 1

#ifdef TESTMODE
#include "audio_pipeline/test_tone.h"
#endif
#include <ES9039Q2M.h>

// Filter control endpoints and steps
#define MIN_GAIN_DB -15.0f
#define MAX_GAIN_DB 15.0f
#define GAIN_STEP_DB 0.1f
#define MIN_Q 0.1f
#define MAX_Q 5.0f
#define Q_STEP 0.1f
#define MIN_FREQUENCY 10.0f
#define LOG_MIN_FREQUENCY (log10f(MIN_FREQUENCY))
#define MAX_FREQUENCY 20000.0f
#define LOG_MAX_FREQUENCY (log10f(MAX_FREQUENCY))
#define FREQ_RESOLUTION 400.0f
#define LOG_FREQ_STEP ((LOG_MAX_FREQUENCY - LOG_MIN_FREQUENCY) / FREQ_RESOLUTION)
#define MASTER_GAIN_STEP_DB 0.1f
#define MASTER_GAIN_MIN -20.0f
#define MASTER_GAIN_MAX 20.0f
#define VOLUME_STEP_DB 1.0f
#define VOLUME_MIN -127.0f
#define VOLUME_MAX 0.0f

// Frequency conversion macros
#define FREQ_TO_INDEX(freq) (map(log10(freq),                       \
                                 LOG_MIN_FREQUENCY,                 \
                                 LOG_MAX_FREQUENCY,                 \
                                 LOG_MIN_FREQUENCY / LOG_FREQ_STEP, \
                                 LOG_MAX_FREQUENCY / LOG_FREQ_STEP))

// Rotary encoder pins
#define FC_PIN_A 33
#define FC_PIN_B 34
#define FILTER_TYPE_PIN 35
#define GAIN_PIN_A 36
#define GAIN_PIN_B 37
#define FILTER_INDEX_PIN 38
#define Q_PIN_A 39
#define Q_PIN_B 40
#define FILTER_MODE_PIN 41
#define INPUT_GAIN_PIN_A 2
#define INPUT_GAIN_PIN_B 3
#define VOLUME_PIN_A 11
#define VOLUME_PIN_B 12
#define UI_MODE_PIN 1

// Settings save interval
#define SAVE_INTERVAL_MS 5000

// Dely before clearing clip indication
#define CLIP_CLEAR_DELAY_MS 100

// DAC initialization retries
#define DAC_INIT_RETRIES 3
#define DAC_INIT_DELAY_MS 200
#define DAC_CHECK_PERIOD 5000

// Meter update interval
#define METER_UPDATE_INTERVAL_MS 50

// DAC instance
ES9039Q2M dac;

// Rotary encoders
AcceleratedEncoder fcSelector(FC_PIN_A, FC_PIN_B);
AcceleratedEncoder gainSelector(GAIN_PIN_A, GAIN_PIN_B);
AcceleratedEncoder qSelector(Q_PIN_A, Q_PIN_B);
AcceleratedEncoder masterGainSelector(INPUT_GAIN_PIN_A, INPUT_GAIN_PIN_B);
AcceleratedEncoder volumeSelector(VOLUME_PIN_A, VOLUME_PIN_B);

// Pushbuttons
OneButton filterSelectButton(FILTER_INDEX_PIN, true);
OneButton filterTypeSelectButton(FILTER_TYPE_PIN, true);
OneButton displayModeButton(FILTER_MODE_PIN, true);
OneButton uiModeButton(UI_MODE_PIN, true);

AudioSquareWave waveform;
#ifdef TESTMODE
TestTone testTone(100, 48000);
#endif

// The filters
AudioFilterBiquadFloat filter;

AudioGain gain;
AudioRMS rmsMeter;
AudioPeak peakMeter;
AudioSpectrumTD spectrum;

ControlValues controlValues(filter);
Display display;

// Last time settings were saved to EEPROM
unsigned long lastSaveTime = 0;
bool saveNeeded = false;

// DAC state
bool dacRunning = false;

// Clipping state
typedef enum ClipState
{
  NO_CLIP,
  CLIP_TRIGGERED,
  CLIP_ACTIVE
} ClipState;

ClipState clipState = NO_CLIP;
uint32_t clipTimestamp = 0;

bool checkDAC()
{
  return dac.getChipID() != 0;
}

/**
 * @brief Initializes the ES9039Q2M DAC with default settings.
 *
 * This function performs a reset of the DAC, applies initial configuration settings,
 * and sets the initial volume level based on the global `volume` variable.
 *
 * @note The DAC is reset by writing 0x82 to register 0x00, followed by a delay of 500 ms.
 * @note Initial configuration includes setting system config, volume, and other necessary
 *       registers for proper operation.
 * @note The volume is set in decibels (dB) using the setVolumeDB() method of the DAC class.
 */
void initDAC()
{
  // Reset the DAC
  for (int i = 0; i < DAC_INIT_RETRIES; i++)
  {
    dac.writeRegister8(0x00, 0x82);
    delay(DAC_INIT_DELAY_MS);
    if (checkDAC() != 0)
    {
      dacRunning = true;
      break; // Exit loop if DAC responds
    }
  }
  if (!dacRunning)
  {
    Serial.println("Failed to initialize DAC after multiple attempts.");
    return;
  }

  // Initial settings
  dac.writeRegister8(0x00, 0x02);
  // Configure DAC for externally clocked PCM (I2S slave pipeline).

  // DO NOT CHANGE!
  dac.writeRegister8(0x00, 0x02);
  dac.writeRegister8(0x01, 0xB1);
  dac.writeRegister8(0x39, 0x41); // 41
  dac.writeRegister8(0x56, 0x00);
  dac.writeRegister8(0x7B, 0x00);
  // END DO NOT CHANGE!
  dac.setVolumeDB(controlValues.getVolume());
}

/**
 * @brief Updates the filter coefficients for the selected filter band.
 *
 * This function configures both left and right channel filters based on the
 * filter type and parameters stored in the filterSettings array for the
 * specified band.
 *
 * @param selected The index of the filter band to update
 *
 * @note The function applies the same filter settings to both left and right
 *       channels to maintain stereo coherence.
 * @note Supported filter types: LOWSHELF, HIGHSHELF, PEAKINGEQ, and BYPASS
 */
void updateFilter(int selected)
{
  FilterSettings settings = controlValues.getFilter(selected);
  if (!isfinite(settings.frequency) || !isfinite(settings.Q) || !isfinite(settings.gain))
  {
    filter.bypass(selected);
    return;
  }
  switch (settings.type)
  {
  case LOWSHELF:
    filter.setLowShelf(selected, settings.frequency, AudioController::getSampleRate(), settings.gain, settings.Q);
    break;
  case HIGHSHELF:
    filter.setHighShelf(selected, settings.frequency, AudioController::getSampleRate(), settings.gain, settings.Q);
    break;
  case PEAKINGEQ:
    filter.setPeakingEQ(selected, settings.frequency, AudioController::getSampleRate(), settings.Q, settings.gain);
    break;
  case BYPASS:
    filter.bypass(selected);
  }
}

/**
 * @brief Updates all filter bands by applying the current settings.
 *
 * This function iterates through all filter bands defined by FILTER_BANDS
 * and calls updateFilter() for each band to ensure that the filter
 * coefficients are up to date based on the current settings.
 */
void updateAllFilters()
{
  for (int i = 0; i < FILTER_BANDS; i++)
  {
    updateFilter(i);
  }
}

void clipDetected(bool clipped)
{
  if (clipped)
  {
    if (clipState == NO_CLIP)
    {
      clipState = CLIP_TRIGGERED;
    }
  }
}

void initDisplay()
{
  // Mark the initial settings a non-user input to avoid triggering any animations or highlights on the display.
  display.setUserInput(false);
  display.setMasterGain(controlValues.getMasterGain());
  display.setVolume(controlValues.getVolume());
  display.setUIMode(controlValues.getUIMode());
  updateAllFilters();
  display.commit();

  // Anything from this point on is user input
  display.setUserInput(true);
  display.commit();
}

/**
 * @brief Initializes the audio processing system, UI controls, and hardware interfaces.
 *
 * This function sets up the following components:
 * - Serial communication at 115000 baud
 * - Audio memory allocation (12 blocks)
 * - Waveform generator configured as square wave at 980 Hz with 0.3 amplitude
 * - Rotary encoder pins for frequency control (FC), gain, Q factor, and filter index
 * - Filter type selection button with pull-up resistor
 * - Frequency selector with range 2-2000 Hz, initialized at 100 (1 kHz)
 * - Gain selector initialized to PEAKINGEQ mode
 * - Q factor selector initialized to 707 (Q=0.707)
 * - Filter type button callback to cycle through 3 filter types
 * - I2C communication via Wire interface
 * - Additional analog inputs (A10, A11, A12) and digital pin 10 as chip select
 * - Audio mixer gains set to 0.5 for both left and right channels
 */
void setup(void)
{
  Serial.begin(115000);

  gain.setTimingName("gain");
  filter.setTimingName("filter_biquad");
  rmsMeter.setTimingName("rms");
  peakMeter.setTimingName("peak");
  spectrum.setTimingName("spectrum_td");
  AudioController::getInstance()->setTimingName("audio_controller");

  // Build audio pipeline
  // Source -> Gain -> Filter -> I2S
  gain.addReceiver(&filter);
  filter.addReceiver(&rmsMeter);
  filter.addReceiver(&peakMeter);
  filter.addReceiver(&spectrum);
  filter.addReceiver(AudioController::getInstance());
  gain.setGain(1.0f);
  spectrum.configure(FFT_DISPLAY_BINS, 48000, 20.0, 20000.0,
                     AudioSpectrumTD::Spacing::Logarithmic,
                     AudioSpectrumTD::Detector::Peak,
                     1.0, 20.0 * log10(5.0));  // linear gain x5
  spectrum.setEnabled(true);

#ifdef TESTMODE
  testTone.addReceiver(&gain);
  AudioController::getInstance()->addReceiver(&testTone);
#else
  AudioController::getInstance()->addReceiver(&gain);
#endif
  AudioController::getInstance()->setClipDetector(clipDetected);

  // Make sure pins 5 and 6 are in input mode (due to a PCB design issue)
  pinMode(5, INPUT);
  pinMode(6, INPUT);

  // Initialize the DAC
  dac.begin();
  delay(500); // Wait for DAC to stabilize
  initDAC();

  // need to wait a bit before configuring codec,
  // otherwise something weird happens and there's no output...
  delay(100);

#ifdef TESTMODE
  InitI2s(false);
  AudioController::getInstance()->setSampleRate(96000);

  // testTone.begin();
#else
  InitI2s(true);
#endif
  // waveform.setAmplitude(0.5f);
  // waveform.setFrequency(980.0f); // 980 Hz test tone
  // waveform.addReceiver(&gain);

  // Initialize UI
  // Set all the rotary encoder pints to input mode
  pinMode(FC_PIN_A, INPUT);
  pinMode(FC_PIN_B, INPUT);
  pinMode(FILTER_TYPE_PIN, INPUT_PULLUP);
  pinMode(GAIN_PIN_A, INPUT);
  pinMode(GAIN_PIN_B, INPUT);
  pinMode(FILTER_INDEX_PIN, INPUT);
  pinMode(Q_PIN_A, INPUT);
  pinMode(Q_PIN_B, INPUT);
  pinMode(INPUT_GAIN_PIN_A, INPUT_PULLUP);
  pinMode(INPUT_GAIN_PIN_B, INPUT_PULLUP);

  // Initialize clip LED
  pinMode(LED_BUILTIN, OUTPUT);

  // Set up pushbuttons
  filterTypeSelectButton.attachPress([]()
                                     { controlValues.cycleFilterType(); });
  filterSelectButton.attachPress([]()
                                 { controlValues.cycleSelectedBand(); });
  displayModeButton.attachPress([]()
                                { controlValues.cycleDisplayMode(); });
  uiModeButton.attachPress([]()
                           { controlValues.cycleUIMode(); });

  // Initialize S2C
  Wire.begin();

  // Set up Q control on A10
  pinMode(A10, INPUT);
  pinMode(A11, INPUT);
  pinMode(A12, INPUT);
  pinMode(10, OUTPUT);

  // Reset last save time
  lastSaveTime = millis();

  // Load persisted settings
  PersistedSettings persistedSettings;
  if (loadSettings(persistedSettings))
  {
    for (int i = 0; i < FILTER_BANDS; i++)
    {
      controlValues.setFilterSettings(i, persistedSettings.filterSettings[i]);
    }
    controlValues.setSelectedBand(persistedSettings.selectedFilterBand);
    controlValues.setDisplayMode(persistedSettings.displayMode);
    controlValues.setMasterGain(persistedSettings.masterGain);
    controlValues.setVolume(persistedSettings.volume);
    gain.setGain(powf(10.0f, controlValues.getMasterGain() / 20.0f));
    dac.setVolumeDB(controlValues.getVolume());
    Serial.println("Loaded persisted settings from EEPROM.");
  }
  else
  {
    // Initialize default settings
    Serial.println("No persisted settings found, using defaults.");
    for (int i = 0; i < FILTER_BANDS; i++)
    {
      FilterSettings settings;
      settings.frequency = 1000.0f; // 1 kHz
      settings.Q = 0.707f;          // Q=0.707
      settings.gain = 0.0f;         // 0 dB
      settings.type = BYPASS;       // Bypass
      controlValues.setFilterSettings(i, settings);
    }
  }

  // Set initial positions — setEndpoints MUST come before setAcceleratedPosition so
  // the clamping inside setAcceleratedPosition uses the correct range.
  FilterSettings settings = controlValues.getCurrentFilter();
  Serial.printf("Selected filter: %d, Initial frequency: %f Hz, Q: %f, Gain: %f dB, Index: %d\n",
                controlValues.getSelectedBand(), settings.frequency, settings.Q, settings.gain, FREQ_TO_INDEX(settings.frequency));
  fcSelector.setEndpoints(log10(MIN_FREQUENCY) / LOG_FREQ_STEP,
                          log10(MAX_FREQUENCY) / LOG_FREQ_STEP);
  fcSelector.setAcceleratedPosition(FREQ_TO_INDEX(settings.frequency));
  gainSelector.setEndpoints(MIN_GAIN_DB / GAIN_STEP_DB, MAX_GAIN_DB / GAIN_STEP_DB);
  gainSelector.setAcceleratedPosition(settings.gain / GAIN_STEP_DB);
  qSelector.setEndpoints(MIN_Q / Q_STEP, MAX_Q / Q_STEP);
  qSelector.setAcceleratedPosition(settings.Q / Q_STEP);
  masterGainSelector.setEndpoints(
      MASTER_GAIN_MIN / MASTER_GAIN_STEP_DB,
      MASTER_GAIN_MAX / MASTER_GAIN_STEP_DB); // -20 dB to 20 dB
  masterGainSelector.setAcceleratedPosition(controlValues.getMasterGain() / MASTER_GAIN_STEP_DB);
  volumeSelector.setEndpoints(VOLUME_MIN / VOLUME_STEP_DB, VOLUME_MAX / VOLUME_STEP_DB);
  volumeSelector.setAcceleratedPosition(controlValues.getVolume() / VOLUME_STEP_DB);

  // Initial display update
  updateAllFilters();
  delay(500); // Wait for display to be fully initialized
  initDisplay();
}

/**
 * This function is called from the loop and blinks the buiitin LED once a second.
 */
void blinkLED()
{
  static time_t nextToggle = 0;
  static bool state = false;
  time_t currentTime = millis();
  if (currentTime >= nextToggle)
  {
    digitalWrite(LED_BUILTIN, state ? HIGH : LOW);
    Serial.printf("Flipped state to %d\n", state);
    nextToggle = currentTime + 500; // Toggle every second
  }
}

uint32_t getCurrentSampleRate(bool *isChanged = nullptr)
{
  static uint32_t lastRate = 44100; // Default to 44.1 kHz until we get a reading from AudioController
  uint32_t newRate = AudioController::getStandardizedSampleRate();
  if (isChanged)
  {
    *isChanged = (newRate != lastRate);
  }
  if (AudioController::isSampleRateStable())
  {
    lastRate = newRate;
  }
  return newRate;
}

void checkDACConnection(time_t currentTime, time_t &lastDACCheck)
{
  if (currentTime - lastDACCheck <= DAC_CHECK_PERIOD)
  {
    return;
  }

  if (!checkDAC())
  {
    dacRunning = false;
    Serial.println("Lost contact with DAC!.");
  }
  else if (!dacRunning)
  {
    Serial.println("DAC came back online. Re-initializing.");
    initDAC();
    digitalWrite(LED_BUILTIN, LOW);
  }

  lastDACCheck = currentTime;
}

void updateSampleRateStatus(uint32_t &lastSampleRate, bool &lastSampleRateStable)
{
  uint32_t currentSampleRate = AudioController::getStandardizedSampleRate();
  bool currentSampleRateStable = AudioController::isSampleRateStable();
  if (currentSampleRate == lastSampleRate &&
      currentSampleRateStable == lastSampleRateStable)
  {
    return;
  }

  // Retune only when stable to avoid invalid coefficients during clock transients.
  if (currentSampleRateStable)
  {
    updateAllFilters();
    spectrum.configure(FFT_DISPLAY_BINS, currentSampleRate, 20.0, 20000.0,
                       AudioSpectrumTD::Spacing::Logarithmic,
                       AudioSpectrumTD::Detector::RMS,
                       1.0, 20.0 * log10(5.0));  // linear gain x5
  }

  lastSampleRate = currentSampleRate;
  lastSampleRateStable = currentSampleRateStable;
  display.setSampleRate(currentSampleRate, true);
  display.commit();
  Serial.printf("Sample rate changed: %u Hz (stable=%s)\n",
                currentSampleRate,
                currentSampleRateStable ? "true" : "false");
}

void printStatusIfNeeded(time_t currentTime, time_t &nextStatusPrint)
{
  static uint32_t lastProcessCount = 0;

  if (currentTime < nextStatusPrint)
  {
    return;
  }

  Serial.println("----- Status -----");
  float avgCpuLoadPct = Timers::GetCpuLoad() * 100.0f;
  float peakCpuLoadPct = 0.0f;
  float avgPeriod = Timers::GetAvgPeriod();
  float avgProcUs = Timers::GetAvg(Timers::TIMER_TOTAL);
  float peakProcUs = Timers::GetPeak(Timers::TIMER_TOTAL);
  const float cpuHz = 600000000.0f; // Teensy 4.x nominal core clock
  float avgCycles = avgProcUs * (cpuHz / 1000000.0f);
  float peakCycles = peakProcUs * (cpuHz / 1000000.0f);
  float budgetCycles = avgPeriod * (cpuHz / 1000000.0f);
  float avgHeadroomPct = 0.0f;
  if (avgPeriod > 0.0f)
  {
    peakCpuLoadPct = (Timers::GetPeak(Timers::TIMER_TOTAL) / avgPeriod) * 100.0f;
    avgHeadroomPct = ((avgPeriod - avgProcUs) / avgPeriod) * 100.0f;
  }
  Serial.printf(
      "CPU Load avg: %.2f%%, peak: %.2f%%, Sample rate: %u Hz, stable: %s, stable intervals: %u, inputAlign: %s (%u-bit)\n",
      avgCpuLoadPct,
      peakCpuLoadPct,
      AudioController::getStandardizedSampleRate(),
      AudioController::isSampleRateStable() ? "true" : "false",
      AudioController::getNumStableIntervals(),
      AudioController::isInputAlignmentLocked() ? "locked" : "unlocked",
      (unsigned)AudioController::getInputShiftBits());
  Serial.printf(
      "Frame timing us (avg/peak/budget): %.2f / %.2f / %.2f, cycles (avg/peak/budget): %.0f / %.0f / %.0f, avg headroom: %.2f%%\n",
      avgProcUs,
      peakProcUs,
      avgPeriod,
      avgCycles,
      peakCycles,
      budgetCycles,
      avgHeadroomPct);
  nextStatusPrint = currentTime + 2000;
  Serial.printf("RMS Level: %f, / %f, peak: %f / %f\n", rmsMeter.getRMSLeft(), rmsMeter.getRMSRight(), peakMeter.getPeakLeft(), peakMeter.getPeakRight());
  if (controlValues.getUIMode() != UI_MODE_SIMPLE)
  {
    peakMeter.reset();
  }
  uint32_t processCount = AudioController::getProcessCount();
  Serial.printf("Audio blocks processed: %lu (+%lu)\n",
                (unsigned long)processCount,
                (unsigned long)(processCount - lastProcessCount));
  lastProcessCount = processCount;
  Serial.printf("DAC is %s\n", dac.getChipID() == 99 ? "alive" : "dead");
  AudioComponent::printTimingReport();
}

void updateClipIndicator()
{
  if (!dacRunning)
  {
    return;
  }

  if (clipState == CLIP_TRIGGERED)
  {
    clipState = CLIP_ACTIVE;
    clipTimestamp = millis();
    digitalWrite(LED_BUILTIN, HIGH);
  }
  else if (clipState == CLIP_ACTIVE && (millis() - clipTimestamp) > CLIP_CLEAR_DELAY_MS)
  {
    clipState = NO_CLIP;
    digitalWrite(LED_BUILTIN, LOW);
  }
}

void tickControls()
{
  fcSelector.tick();
  gainSelector.tick();
  qSelector.tick();
  filterTypeSelectButton.tick();
  filterSelectButton.tick();
  uiModeButton.tick();
  displayModeButton.tick();
  masterGainSelector.tick();
  volumeSelector.tick();
}
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
void loop(void)
{
  static uint32_t lastSampleRate = 0;
  static bool lastSampleRateStable = false;
  static time_t nextStatusPrint = 0;
  static time_t lastDACCheck = 0;
  static time_t lastMeterUpdate = 0;
  time_t currentTime = millis();

  if (currentTime - lastMeterUpdate >= METER_UPDATE_INTERVAL_MS)
  {
    if (controlValues.getUIMode() == UI_MODE_SIMPLE)
    {
      display.setVUMeterValue(peakMeter.getPeakLeft(), peakMeter.getPeakRight());
      //display.setVUMeterValue(rmsMeter.getRMSLeft(), rmsMeter.getRMSRight());
      peakMeter.reset();
      display.commit();
    } else if (controlValues.getUIMode() == UI_MODE_FFT)
    {
      float fqBins[FFT_DISPLAY_BINS];
      spectrum.getNormalizedBins(fqBins, FFT_DISPLAY_BINS);
      display.setFFTValues(fqBins, true);
      display.commit();
    }
    lastMeterUpdate = currentTime;
  }

  // Is the DAC still connected? If not, blink the LED and keep checking until it comes back
  checkDACConnection(currentTime, lastDACCheck);
  if (!dacRunning)
  {
    blinkLED();
  }

  updateSampleRateStatus(lastSampleRate, lastSampleRateStable);
  printStatusIfNeeded(currentTime, nextStatusPrint);
  updateClipIndicator();
  tickControls();

  // If the selected band changed, we need to sync the encoder positions to the new band's settings

  readControlValues(controlValues);
  // Serial.printf("DIrty flags - dirty: %d, bandChanged: %d, filterChanged: %d\n",
  //               controlValues.isDirty(),
  //               controlValues.isBandChanged(),
  //               controlValues.isFilterChanged());
  if (!controlValues.isDirty())
  {
    saveSettingsIfNeeded(currentTime);
    return;
  }
  if (controlValues.isFilterChanged())
  {
    syncEncoders();
    updateFilter(controlValues.getSelectedBand());
  }
  gain.setGain(powf(10.0f, controlValues.getMasterGain() / 20.0f));
  dac.setVolumeDB(controlValues.getVolume());
  display.update(controlValues);
  display.commit();
  controlValues.reset();

  saveNeeded = true;
}

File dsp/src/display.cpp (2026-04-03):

// Copyright (c) 2026 Pontus Rydin
// SPDX-License-Identifier: MIT
//
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
// THE SOFTWARE IS PROVIDED "AS IS", WITHOUT WARRANTY OF ANY KIND, EXPRESS OR
// IMPLIED, INCLUDING BUT NOT LIMITED TO THE WARRANTIES OF MERCHANTABILITY,
// FITNESS FOR A PARTICULAR PURPOSE AND NONINFRINGEMENT. IN NO EVENT SHALL THE
// AUTHORS OR COPYRIGHT HOLDERS BE LIABLE FOR ANY CLAIM, DAMAGES OR OTHER
// LIABILITY, WHETHER IN AN ACTION OF CONTRACT, TORT OR OTHERWISE, ARISING FROM,
// OUT OF OR IN CONNECTION WITH THE SOFTWARE OR THE USE OR OTHER DEALINGS IN THE
// SOFTWARE.
#include "display.h"

#include "audio_pipeline/audio_controller.h"
#include "netconv.h"
#include <algorithm>
#include <Wire.h>

namespace
{
constexpr uint32_t kStartupDisplaySampleRate = 44100;
}


void Display::sendRegister(uint8_t reg, uint32_t value, bool force)
{
  if(!force && value == registerCache[reg]) {
    return;
  }
  Wire.beginTransmission(DISPLAY_I2C_ADDRESS);
  Wire.write(reg);
  Wire.write((uint8_t *)&value, sizeof(value));
  Wire.endTransmission();
  registerCache[reg] = value;
}

void Display::setFilterBand(int band, bool force)
{
  sendRegister(REG_FILTER_SELECT, htonl(band), force); 
}

void Display::setFilterSettings(FilterSettings *settings, const sample_t *coeffs, bool force)
{
  if(!settings) {
    return;
  }
  sendRegister(REG_FILTER_TYPE, htonl(settings->type), force);
  sendRegister(REG_FILTER_FREQ, htonf(settings->frequency), force);
  sendRegister(REG_FILTER_Q, htonf(settings->Q), force);
  sendRegister(REG_FILTER_GAIN, htonf(settings->gain), force);
  sendRegister(REG_FILTER_COEFF0, htonf(coeffs[0]), force);
  sendRegister(REG_FILTER_COEFF1, htonf(coeffs[1]), force);
  sendRegister(REG_FILTER_COEFF2, htonf(coeffs[2]), force);
  sendRegister(REG_FILTER_COEFF3, htonf(-coeffs[3]), force);
  sendRegister(REG_FILTER_COEFF4, htonf(-coeffs[4]), force);

}

void Display::setDisplayMode(int displayMode, bool force)
{
  Serial.printf("Setting display mode to %d\n", displayMode);
  sendRegister(REG_DISPLAY_MODE, htonl(displayMode), force);
}

void Display::setMasterGain(float masterGain, bool force)
{
  Serial.printf("Setting master gain to %.2f\n", masterGain);
  sendRegister(REG_IN_GAIN, htonf(masterGain), force);
}

void Display::setVolume(float volume, bool force)
{
  sendRegister(REG_OUT_GAIN, htonf(volume), force);
}

void Display::setSampleRate(int sampleRate, bool force)
{
  sendRegister  (
      REG_SAMPLE_RATE,
      htonl(
          AudioController::isSampleRateStable()
              ? AudioController::getStandardizedSampleRate()
              : 0),
      force);
}

void Display::update(ControlValues &controlValues) {
  if(!controlValues.isDirty()) {
    return;
  }
  if(controlValues.isFilterChanged()) {
    if(controlValues.isBandChanged()) {
      setFilterBand(controlValues.getSelectedBand());
    }
    setFilterSettings(&controlValues.getCurrentFilter(), controlValues.getCoefficients());
  }
  setDisplayMode(controlValues.getDisplayMode());
  setMasterGain(controlValues.getMasterGain());
  setVolume(controlValues.getVolume());
  setUIMode(controlValues.getUIMode());
}

void Display::setVUMeterValue(float left, float right, bool force)
{
  const float clampedLeft = std::clamp(left, 0.0f, 1.0f);
  const float clampedRight = std::clamp(right, 0.0f, 1.0f);
  const uint16_t leftValue = static_cast<uint16_t>(clampedLeft * 65535.0f + 0.5f);
  const uint16_t rightValue = static_cast<uint16_t>(clampedRight * 65535.0f + 0.5f);
  uint32_t vuValue = (static_cast<uint32_t>(leftValue) << 16) | rightValue;
  sendRegister(REG_VU_METER, htonl(vuValue), force);
}

void Display::setFFTValues(const float *values, bool force)
{
  if(!values) {
    return;
  }
  int reg = REG_FFT_DATA_L0;
  uint32_t acc = 0;  
  for(size_t i = 0; i < FFT_DISPLAY_BINS; i++) {
    float clamped = std::clamp(values[i], 0.0f, 1.0f);
    uint8_t intValue = static_cast<uint8_t>(clamped * 255.0f);
    acc |= intValue << ((i & 0x03) * 8);
    if((i & 0x03) == 3) {
      sendRegister(reg, ntohl(acc), force); 
      reg++;
      acc = 0;
    }
  }
}

void Display::setUIMode(int uiMode, bool force)
{
  sendRegister(REG_UI_MODE, htonl(uiMode), force);
}

void Display::setUserInput(bool isUserInput, bool force)
{
  sendRegister(REG_USER_INPUT, htonl(isUserInput ? 1 : 0), force);
}

void Display::commit()
{
  sendRegister(REG_COMMIT, 1, true);
}

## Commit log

2026-01-04 Create Teensy4i2s
2026-01-06 Doubles phase 1
    [param-eq.kicad_pcb, param-eq.kicad_sch]
2026-03-23 Improved sample rate detection.
2026-03-27 Revert "Merge branch 'main' of https://github.com/prydin/param-eq"
    This reverts commit 389628c2baba959bef1beb1be98a9c41f163846e, reversing
    changes made to 7efa158129df0e81abc05ebdd55c449f5cfdd2da.
    [AcceleratedEncoder.h]
2026-04-02 Filter parameter popup
